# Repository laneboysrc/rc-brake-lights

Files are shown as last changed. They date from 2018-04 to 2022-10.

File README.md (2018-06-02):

# RC Brake & Reversing Light controller

This project is an easy-to-build light controller for Radio Controlled cars that simulates realistic brake and reversing lights.

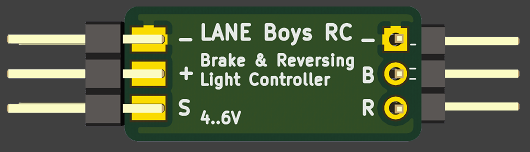
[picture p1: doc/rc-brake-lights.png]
RC Brake Lights circuit board


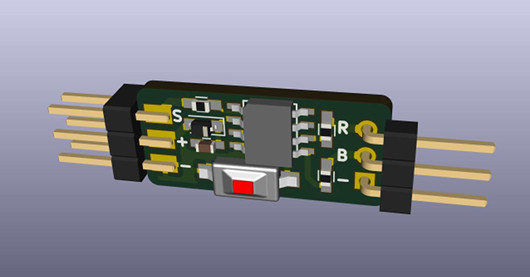
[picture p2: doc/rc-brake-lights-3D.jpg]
RC Brake Lights 3D view


It hooks between your ESC and receiver.

The brake lights automatically turn on for a short, random time when the throttle goes to neutral. The reversing lights turn on when driving backwards.

The light controller supports various ESC modes to ensure the lights are in sync with the way your ESC controls the drive motor.

The aim of the project is to make it easy to build anyone with minimal electronics knowledge. **If you are unable to build it yourself please contact [laneboysrc@gmail.com](mailto:laneboysrc@gmail.com); we'd be happy to sell you one.**

If you are looking for more than just brake lights check out our full-featured [DIY RC Light Controller](https://github.com/laneboysrc/rc-light-controller).

## Building the electronics

The core of the light controller is the inexpensive STC STC15W104. It is a modern interpretation of the venerable 8051 MCU. This MCU was chosen due to its very low cost and because it can be programmed with an inexpensive USB-to-serial adapter, or using the serial port on a Raspberry Pi.

You can find the STC15W104 usually on eBay, AliExpress, Electrodragon, LCSC ...

Beside the MCU you need 3 resistors, a diode and a capacitor. The complete [list of components](electronics/BOM%20-%20Bill%20of%20Materials.txt) can be found in the `electronics/` folder

For convenience the [schematics are available as PDF file](electronics/rc-brake-lights-schematics.pdf).

Due to the small number of required components, the light controller can be easily built on a perfboard. The following image shows how to wire everything up:

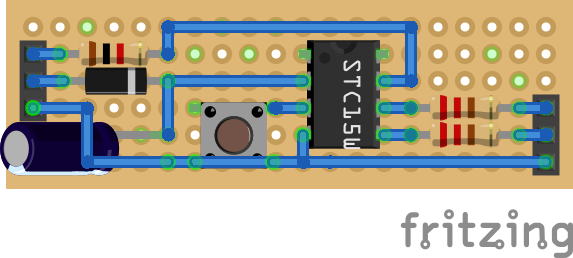
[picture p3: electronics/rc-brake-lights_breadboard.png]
Perfboard construction


(The [Fritzing](http://fritzing.org) source file for this drawing is provided in the `fritzing/` folder)

If you plan to build several controllers it may be worth-while to order printed circuit boards. [Gerber files](gerber-rc-brake-lights.zip) for manufacturing PCBS are provided, as well as the [KiCad source files](electronics/). Note that the PCB uses SMD components rather than through-hole. Still, it is designed for hand-soldering.

## Loading the firmware

You can find the pre-compiled firmware released as part of the project.

If you want to build or modify the firmware you will need [SDCC](http://sdcc.sourceforge.net) and [GNU Make](https://www.gnu.org/software/make/).

To flash the firmware into the STC15W104, use [STCGAL](https://github.com/grigorig/stcgal).

### Loading the firmware with an USB-to-serial adapter

Follow the instructions at [https://github.com/grigorig/stcgal#installation](https://github.com/grigorig/stcgal#installation) to install STCGAL. This programming tool for the STC MCU requires [Python 3](https://www.python.org/downloads/), and the Python 3 libraries `pyserial` and `tqdm`.

- Go to https://www.python.org and download Python; install it.
- Open a Command prompt (run cmd.exe)
- In the command prompt execute `pip install pyserial tqdm`

Connect your USB-to-serial adapter to the RC-brake-lights controller as follows:

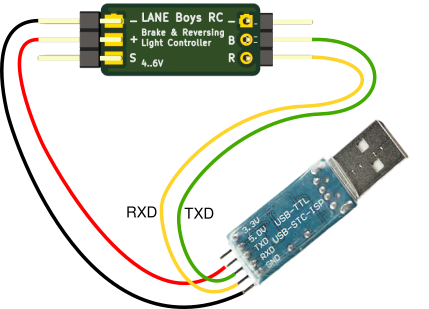
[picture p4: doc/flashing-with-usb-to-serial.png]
Flashing with a USB-to-serial adapter


Do not connect `+` yet, only after starting STCGAL.

Download the [firmware Intel-HEX file](rc-brake-lights.ihx) and execute STCGAL as follows:

    python stcgal.py -t 12000 --option low_voltage_reset=true --option low_voltage_threshold=0 --option eeprom_lvd_inhibit=true -b 1200 -p COM7 rc-brake-lights.ihx

*Important*: Replace the COM port number with the one of your USB-to-serial adapter. In Windows consult the Device Manager to find out which port number to use.

Once started, STCGAL prompts you to power-cycle the circuit. Plug in `+` and STCGAL should find the MCU and program it. Your controller is now ready to use.

### Loading the firmware using a Raspberry Pi

The Raspberry Pi has a serial port accessible on its GPIO pin-header, so we can use it directly for programming.

Connect the RC-brake-lights controller as follows:

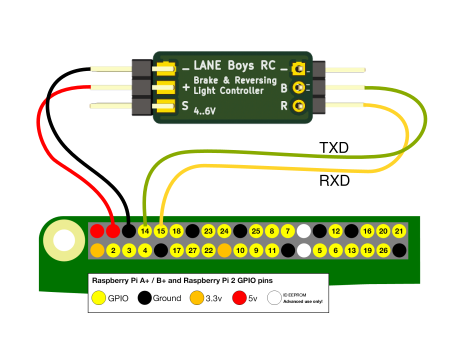
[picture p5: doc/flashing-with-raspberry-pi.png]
Flashing with Raspberry Pi


Do not connect `+` yet, only after starting STCGAL.

Download and unpack STCGAL:

    wget https://github.com/grigorig/stcgal/archive/master.zip
    unzip master.zip

Install the required Python 3 modules:

    sudo apt install python3-serial python3-tqdm

Use `sudo raspi-config` and go to `Interface Options`, then `P6 Serial` where you can disable log-in via the serial console, and enable the serial hardware:

    Would you like a login shell to be accessible over serial? Select NO
    Would you like the serial port hardware to be enabled? Select YES

After rebooting, download the [firmware Intel-HEX file](rc-brake-lights.ihx) and execute STCGAL as follows:

    python3 stcgal-master/stcgal.py -p /dev/ttyAMA0 -t 12000 --option low_voltage_reset=true --option low_voltage_threshold=0 --option eeprom_lvd_inhibit=true -b 1200 rc-brake-lights.ihx

Once started, STCGAL prompts you to power-cycle the MCU. Plug in `+` and STCGAL should find the MCU and program it. Your controller is now ready to use.

## Connecting the light controller to your RC system

The light controller has two parallel connectors on the input side. Connect your ESC to one of the plugs and connect the TH input of the receiver with a male-to-male servo cable  to the other plug.

The `B` output drives two red LEDs in parallel for the brake light function, the `R` output drives two white LEDs in parallel for the reversing light function.

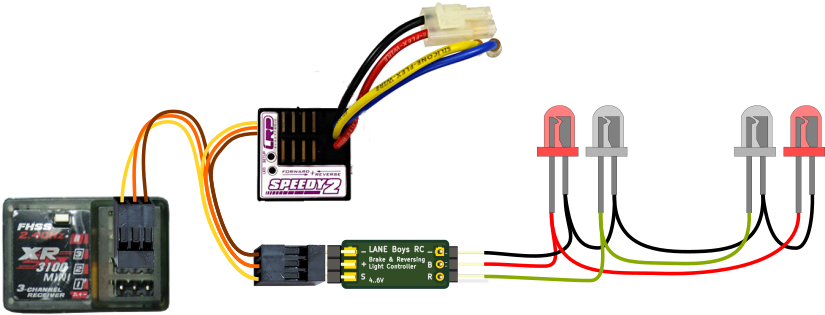
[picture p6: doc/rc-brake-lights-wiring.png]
Wiring diagram


## Forward/Reverse setup

Depending on your RC system, out of the box the light controller may operate in the wrong direction (forward and backward reversed). To change this, press and hold the setup button on the light controller for 3 seconds. The LEDs will start flashing quickly.

Now move the throttle on the transmitter to the driving direction that would make the car move `forward`. When LEDs will go out and the light controller has now learned the correct direction of the throttle signal for `forward`. This setting is preserved, so you only have to do this once.

## Changing the ESC mode

When it comes to brake function, ESC models behave differently. The light controller can be programmed for the specific behavior of your ESC.

To change the ESC mode, perform the following steps:
Press and hold the setup button on the light controller. After 3 seconds, the LEDs will start to flash quickly. Press the setup button one more time. The light controller enters the ESC mode setting and flashes the current ESC mode number:

##### 1 flash: Forward/Brake/Reverse with timeout
When driving forward and then immediately pushing the throttle to reverse, the ESC performs a brake function. The ESC only allows driving backwards if the ESC has remained in neutral position for a few seconds.

Example: The China 320A ESC, HPI SC-15WP

##### 2 flashes: Forward/Brake/Reverse
After going forward and then into reverse, the ESC always performs the brake function -- even if the throttle remained in neutral for a long time.

Example: Tamiya ESCs

##### 3 flashes: Forward/Reverse (Crawler mode)
Crawler ESC with drag brake, where the ESC switches from forward directly
into reverse.

##### 4 flashes: Forward/Brake
ESC in race mode where reversing is not allowed.

Press the setup button repeatedly until the desired ESC mode has been selected. Then press-and hold the setup button until the LEDs stop flashing. The ESC mode has now been persistently stored.

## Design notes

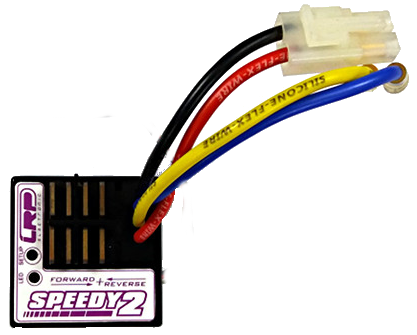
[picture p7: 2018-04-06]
doc/esc.png

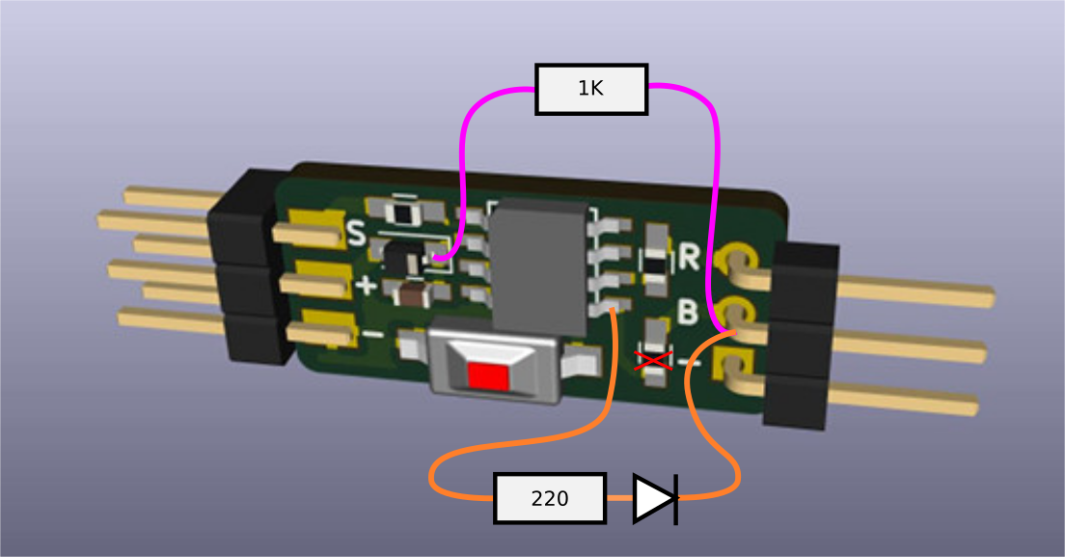
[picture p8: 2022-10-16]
doc/rc-brake-lights-with-tail-light-function.png

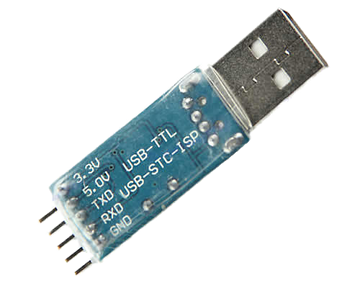
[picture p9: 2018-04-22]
doc/usb-to-serial.png

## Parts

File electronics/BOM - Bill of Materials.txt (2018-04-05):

Partlist for the RC Brake & Reversing Light Controller

Perfboard version with through-hole components
----------------------------------------------

Part  Value      Device            Package           Description
C1    10uF/10V   C-Pol             Radial            Electrolytic capacitor, exact value not important
D1    1N4148     D                 Throughole        Signal diode, must be an ordinary silicon diode, not a Schottky diode
J1               Pin-header        2x3               Pin header for throttle servo input
J2               Pin-header        1x3               Pin header for LED output
R1    1k         R                 Throughhole       Resistor 1/8W or more
R2    220        R                 Throughhole       Resistor 1/8W or more
R2    220        R                 Throughhole       Resistor 1/8W or more
U1    STC15W104  MCU               DIP8              STC Microcontroller, 8051-based, 2.5..5.5V supply range
SW1              SPST                                Push button

PCB version with SMD components
-------------------------------

Part  Value      Device            Package           Description
C1    10uF/10V   C0603             0603              MLCC capacitor X7R or X5R
D1    T4         D                 SOD-123           Signal diode marked T4 (eBay, AliExpress)
J1               Pin-header        2x3               Pin header for throttle servo input
J2               Pin-header        1x3               Pin header for LED output
R1    1k         R                 0603              Resistor
R2    220        R                 0603              Resistor
R2    220        R                 0603              Resistor
U1    STC15W104  MCU               SOP8              STC Microcontroller, 8051-based, 2.5..5.5V supply range
SW1              SPST              3x6x2.5mm         Push button, e.g. https://www.aliexpress.com/item/100pcs-3X6X2-5mm-Tactile-Push-Button-Switch-Tact-Switches-Mini-Micro-Switch-2-Pin-SMD/32814876010.html

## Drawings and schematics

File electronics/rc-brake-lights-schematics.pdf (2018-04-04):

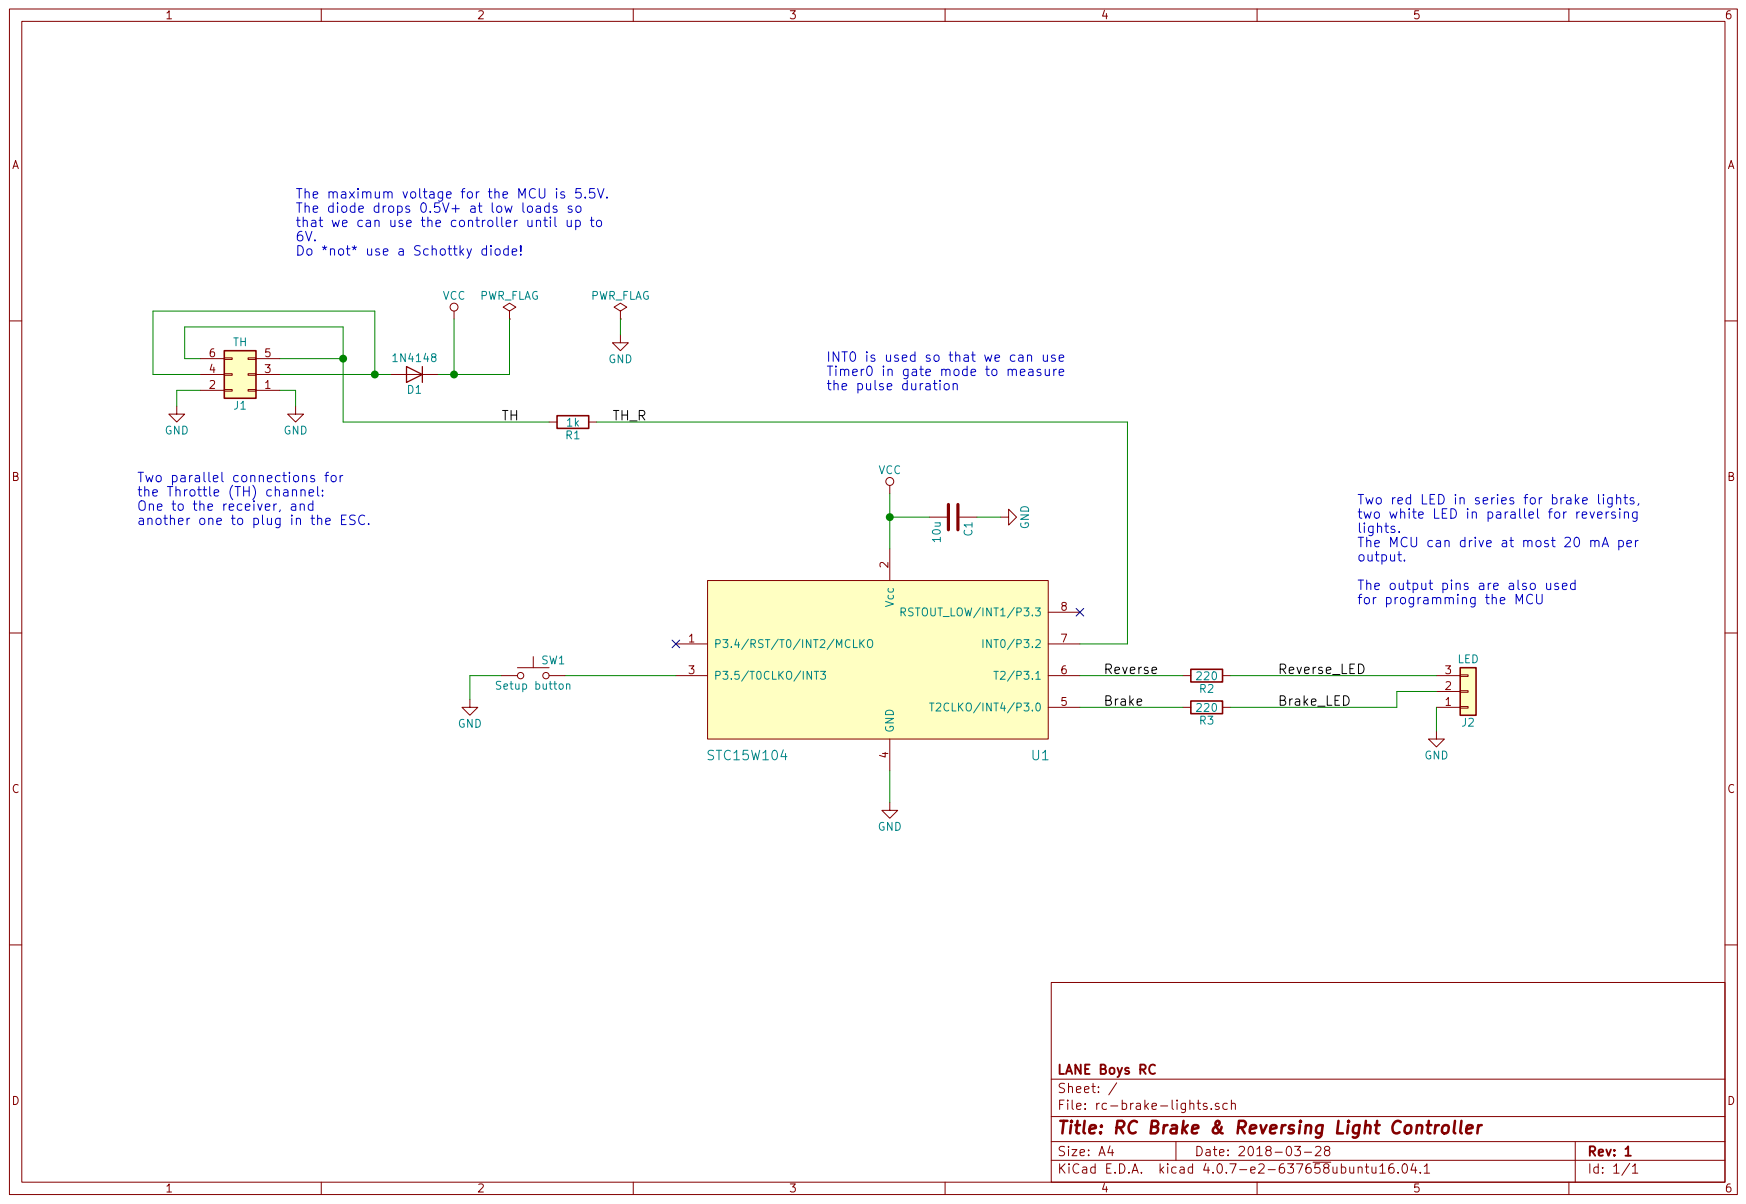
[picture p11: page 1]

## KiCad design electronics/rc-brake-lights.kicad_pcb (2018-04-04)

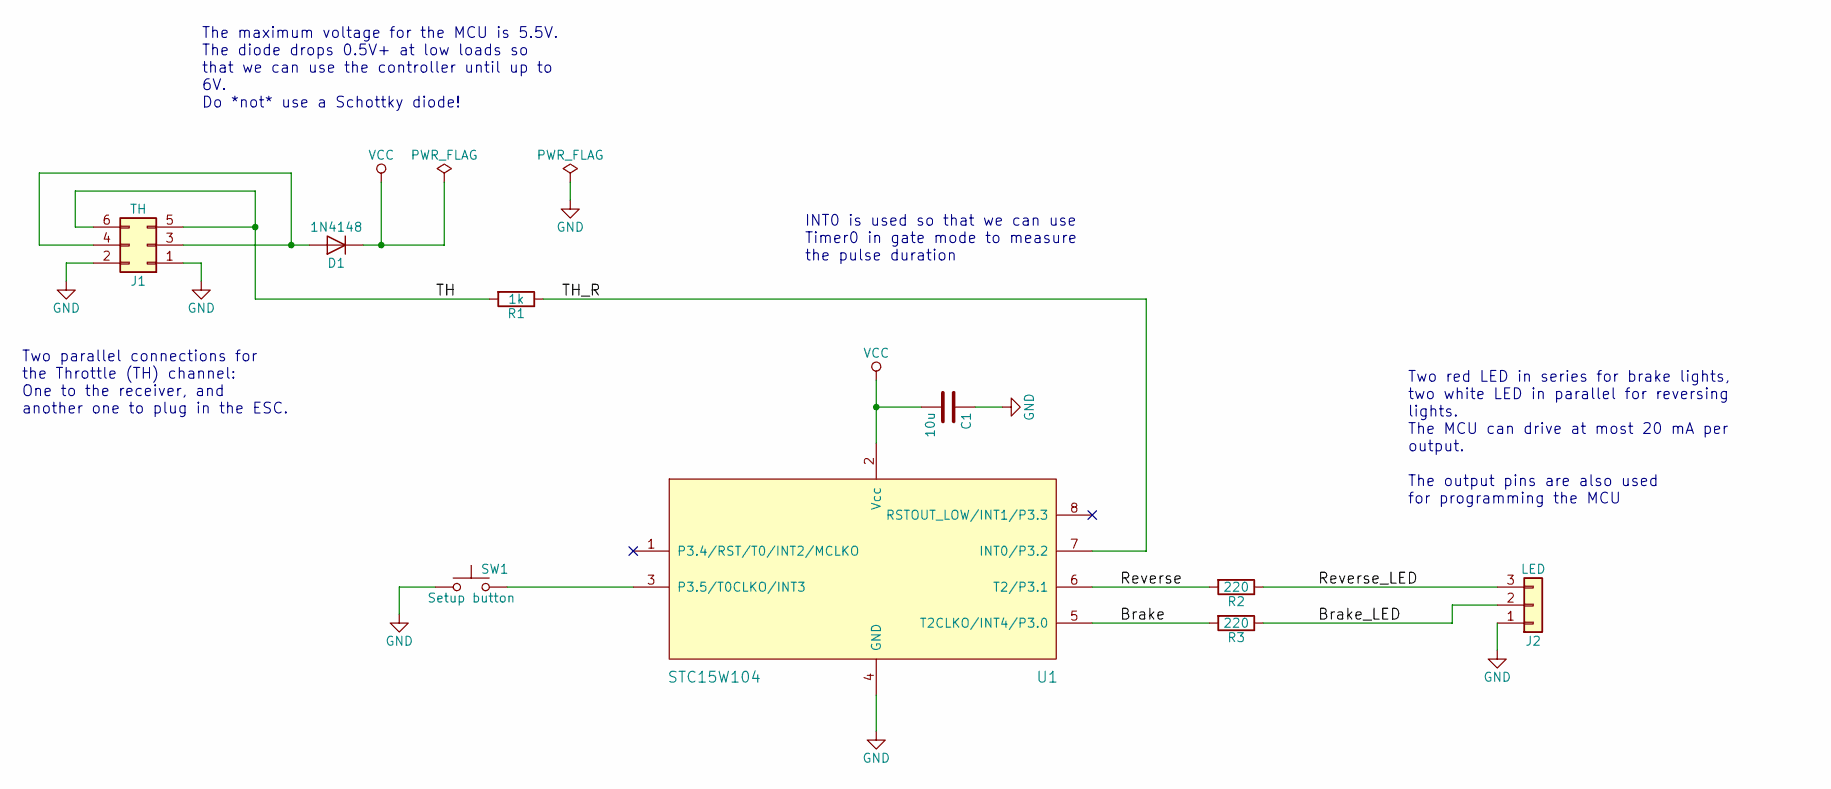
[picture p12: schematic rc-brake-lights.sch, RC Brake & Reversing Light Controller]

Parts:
C1: 10u; C_0603_HandSoldering
D1: 1N4148; D_SOD-323_HandSoldering
J1: TH; Pin_header_02x03_board_edge
J2: LED; Pin_Header_Angled_1x03_Pitch2.54mm
R1: 1k; R_0603_HandSoldering
R2, R3: 220; R_0603_HandSoldering
SW1: Setup button; Tact_switch_SMD_6x3_6x2_5
U1: STC15W104; SOIC-8-N

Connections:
/Brake: R3.2, U1.5 (T2CLKO/INT4/P3.0)
/Brake_LED: J2.2, R3.1
/Reverse: R2.2, U1.6 (T2/P3.1)
/Reverse_LED: J2.3, R2.1
/TH: J1.5, J1.6, R1.2
/TH_R: R1.1, U1.7 (INT0/P3.2)
GND: C1.1, J1.1, J1.2, J2.1, SW1.1, U1.4 (GND)
unnamed: D1.2 (A), J1.3, J1.4
unnamed: SW1.2, U1.3 (P3.5/T0CLKO/INT3)
VCC: C1.2, D1.1 (K), U1.2 (Vcc)

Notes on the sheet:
Two parallel connections for the Throttle (TH) channel: One to the receiver, and another one to plug in the ESC.
Two red LED in series for brake lights, two white LED in parallel for reversing lights. The MCU can drive at most 20 mA per output. The output pins are also used for programming the MCU
The maximum voltage for the MCU is 5.5V. The diode drops 0.5V+ at low loads so that we can use the controller until up to 6V. Do *not* use a Schottky diode!
INT0 is used so that we can use Timer0 in gate mode to measure the pulse duration

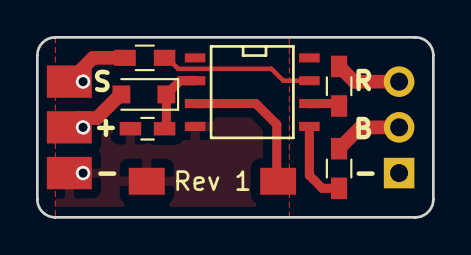
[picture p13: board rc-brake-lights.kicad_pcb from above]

Board: 2 copper layers, 22.0 x 10.0 mm, 9 parts (1 on the bottom side), 10 nets.

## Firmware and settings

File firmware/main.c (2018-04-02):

#include "stdint.h"
#include "stdbool.h"

#include "stc15x10x.h"

#include "globals.h"

#define T2_RELOAD_VALUE ((uint16_t)(0xffff - (__SYSTICK_IN_MS * 1000) + 1))

GLOBAL_FLAGS_T global_flags;
uint32_t entropy;

static volatile bool tick_interrupt_fired;


// ****************************************************************************
static void service_systick(void)
{
    ++entropy;

    global_flags.systick = 0;
    if (tick_interrupt_fired) {
        tick_interrupt_fired = false;
        global_flags.systick = 1;
    }
}


// ****************************************************************************
static void init_softtimer(void)
{
    T2H = T2_RELOAD_VALUE >> 8;
    T2L = T2_RELOAD_VALUE & 0xff;
    AUXR |= 0x10;   // Start Timer2
    IE2 |= 0x04;    // Enable Timer2 interrupt
}


// ****************************************************************************
void main()
{
    global_flags.initializing = true;

    init_lights();
    load_persistent_storage();
    init_softtimer();
    init_servo_reader();

    // Enable interrupts
    EA = 1;

    while (1) {
        service_systick();

        read_all_servo_channels();
        process_drive_mode();
        process_setup();
        process_lights();
    }
}


// ****************************************************************************
extern void extint0(void) __interrupt (0);

void timer2int(void) __interrupt (12)
{
    tick_interrupt_fired = 1;
}

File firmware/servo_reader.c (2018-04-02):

#include <stdint.h>
#include <stdbool.h>

#include "stc15x10x.h"

#include "globals.h"


#define TH_IN INT0

#define SERVO_PULSE_CLAMP_LOW 800
#define SERVO_PULSE_CLAMP_HIGH 2300

#define INITIAL_ENDPOINT_DELTA  250
#define SERVO_PULSE_MIN 600
#define SERVO_PULSE_MAX 2500

#define STARTUP_TIME (2000 / __SYSTICK_IN_MS)


static volatile bool new_data;
static volatile uint16_t raw_data;

static enum {
    INITIALIZE = 0,
    WAIT_FOR_TIMEOUT,
    NORMAL_OPERATION
} servo_reader_state = INITIALIZE;

CHANNEL_T channel[1];


// ****************************************************************************
static void initialize_channel(CHANNEL_T *c) {
    c->endpoint.centre = c->raw_data;
    c->endpoint.left = c->raw_data - INITIAL_ENDPOINT_DELTA;
    c->endpoint.right = c->raw_data + INITIAL_ENDPOINT_DELTA;
}


// ****************************************************************************
static void normalize_channel(CHANNEL_T *c)
{
    if (c->raw_data < SERVO_PULSE_MIN  ||  c->raw_data > SERVO_PULSE_MAX) {
        c->normalized = 0;
        c->absolute = 0;
        return;
    }

    if (c->raw_data < SERVO_PULSE_CLAMP_LOW) {
        c->raw_data = SERVO_PULSE_CLAMP_LOW;
    }

    if (c->raw_data > SERVO_PULSE_CLAMP_HIGH) {
        c->raw_data = SERVO_PULSE_CLAMP_HIGH;
    }

    if (c->raw_data == c->endpoint.centre) {
        c->normalized = 0;
    }
    else if (c->raw_data < c->endpoint.centre) {
        if (c->raw_data < c->endpoint.left) {
            c->endpoint.left = c->raw_data;
        }
        // In order to acheive a stable 100% value we actually calculate the
        // percentage up to 101%, and then clamp to 100%.
        c->normalized = (c->endpoint.centre - c->raw_data) * 101 /
            (c->endpoint.centre - c->endpoint.left);
        if (c->normalized > 100) {
            c->normalized = 100;
        }
        if (!c->reversed) {
            c->normalized = -c->normalized;
        }
    }
    else {
        if (c->raw_data > c->endpoint.right) {
            c->endpoint.right = c->raw_data;
        }
        c->normalized = (c->raw_data - c->endpoint.centre) * 101 /
            (c->endpoint.right - c->endpoint.centre);
        if (c->normalized > 100) {
            c->normalized = 100;
        }
        if (c->reversed) {
            c->normalized = -c->normalized;
        }
    }

    if (c->normalized < 0) {
        c->absolute = -c->normalized;
    }
    else {
        c->absolute = c->normalized;
    }
}


// ****************************************************************************
void init_servo_reader(void)
{
    // Setup timer 0 with a clock of 1 MHz. We run the CPU at 12 MHz, so the
    // default divide by 12 gives us just that.

    TMOD = 0x09;        // Use Timer0 Mode 1, enable gate mode of INT0
    TL0 = TH0 = 0;

    TH_IN = 1;          // Make the TH an input (weak pull-up)
    IT0 = 1;            // INT0 on falling edge only
}


// ****************************************************************************
void read_all_servo_channels(void)
{
    static uint8_t servo_reader_timer;
    static uint8_t remaining_pulse_count;

    bool new_channel_data = false;

    if (global_flags.systick) {
        if (servo_reader_timer) {
            --servo_reader_timer;
        }
    }

    if (new_data) {
        channel[TH].raw_data = raw_data;
        new_channel_data = true;

        new_data = false;
    }

    switch (servo_reader_state) {
        case INITIALIZE:
            // Start Timer0 and enable INT0
            TR0 = 1;
            EX0 = 1;

            servo_reader_timer = STARTUP_TIME;
            servo_reader_state = WAIT_FOR_TIMEOUT;
            remaining_pulse_count = 50;
            break;

        case WAIT_FOR_TIMEOUT:
            if (new_channel_data) {
                if (remaining_pulse_count) {
                    --remaining_pulse_count;
                }
            }

            // Initialization is finished if START_UP time has passed and
            // more than 50 servo pulses have been received. This way we ensure
            // the RC system is up-and-running.
            //
            // At that point we take the throttle value as "neutral position"
            if (servo_reader_timer == 0  &&  remaining_pulse_count == 0) {
                initialize_channel(&channel[TH]);

                servo_reader_state = NORMAL_OPERATION;
                global_flags.initializing = 0;
            }
            break;

        case NORMAL_OPERATION:
            if (new_channel_data) {
                normalize_channel(&channel[TH]);
                global_flags.new_channel_data = true;
            }
            break;

        default:
            servo_reader_state = INITIALIZE;
            break;
    }
}


// ****************************************************************************
// Interrupt triggered by the negative edge of the servo pulse
void extint0() __interrupt (0)
{
    // Only store new data if the last one was taken out already and
    // Timer0 was not overflowing.
    if (!new_data && !TF0) {
        new_data = 1;
        raw_data = (TH0 << 8) | TL0;
    }

    TH0 = TL0 = 0;
    TF0 = 0;
}

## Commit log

2018-03-27 PCB draft
    [BOM.ods, rc-brake-lights.kicad_pcb, rc-brake-lights.sch]
2018-04-01 Move IO pins so we can use T0 to measure pulse width
    [rc-brake-lights.kicad_pcb, rc-brake-lights.sch]
2018-04-01 Basic brake/reverse functionality implemented
    [main.c, servo_reader.c]
2018-04-01 Add setup button
    [rc-brake-lights.kicad_pcb, rc-brake-lights.sch]
2018-04-02 Round-off the PCB edge
    [rc-brake-lights.kicad_pcb]
2018-04-02 Fix ESC mode description
2018-04-03 Make output connector right-angle
    [rc-brake-lights.kicad_pcb, rc-brake-lights.sch]
2018-04-04 Add low voltage reset
2018-04-04 Remove BOM file
    [BOM.ods]
2018-04-04 Add schematics and Gerbers sent for manufactoring
    [rc-brake-lights.kicad_pcb, rc-brake-lights.sch]
2018-04-04 Add Fritzing file
    [rc-brake-lights.fzz]
2018-04-05 Add BOM and breadboard drawing
    [rc-brake-lights.fzz]
2018-04-05 Add wiring diagram
2018-04-06 Update wiring diagram with ESC
2018-04-15 Set low power threshold for STC15W104
    Before we were using settings for STC15F104
